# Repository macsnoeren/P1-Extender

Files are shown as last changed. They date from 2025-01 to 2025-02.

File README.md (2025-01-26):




# P1-Extender

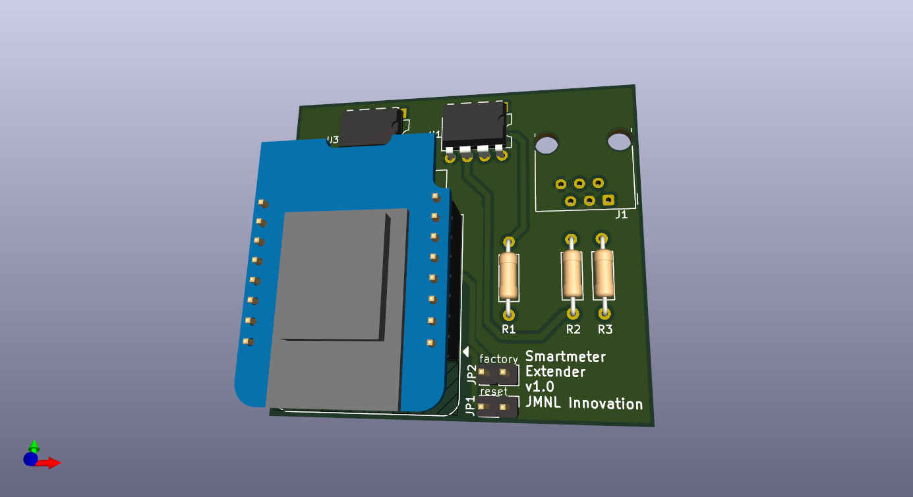
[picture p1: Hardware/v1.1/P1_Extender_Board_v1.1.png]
P1-Extender-Board


## Need your smart meter P1 port far away?
When you charging point is far away from your smartmeter and it needs a P1 poort connection to perform load balancing AND you are not able to use long wires? Than you can use this P1 extender. It connects with the network or Internet and read the messages from your smart meter (using another smart meter P1 reader). It provide these messages similarly to the smart meter. Just connect your charger point to this remote P1 port and it will get the P1 messages.

The hardware and software simulate a smart meter P1 port.

-- In progress

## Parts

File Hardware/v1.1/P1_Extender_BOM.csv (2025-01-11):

Reference | Value | Datasheet | Footprint | Qty | DNP
J1 | RJ12 | ~ | Connector_RJ:RJ12_Amphenol_54601-x06_Horizontal | 1
JP1 | Reset | ~ | Connector_PinHeader_2.54mm:PinHeader_1x02_P2.54mm_Vertical | 1
R1 | 165-200 (180) | ~ | Resistor_THT:R_Axial_DIN0207_L6.3mm_D2.5mm_P10.16mm_Horizontal | 1
R2 | 100 | ~ | Resistor_THT:R_Axial_DIN0207_L6.3mm_D2.5mm_P10.16mm_Horizontal | 1
R3 | 220-330 (330) | ~ | Resistor_THT:R_Axial_DIN0207_L6.3mm_D2.5mm_P10.16mm_Horizontal | 1
U1,U3 | 6N137 | https://docs.broadcom.com/docs/AV02-0940EN | Package_DIP:DIP-8_W7.62mm | 2
U2 | WeMos_D1_mini | https://wiki.wemos.cc/products:d1:d1_mini#documentation | Module:WEMOS_D1_mini_light | 1

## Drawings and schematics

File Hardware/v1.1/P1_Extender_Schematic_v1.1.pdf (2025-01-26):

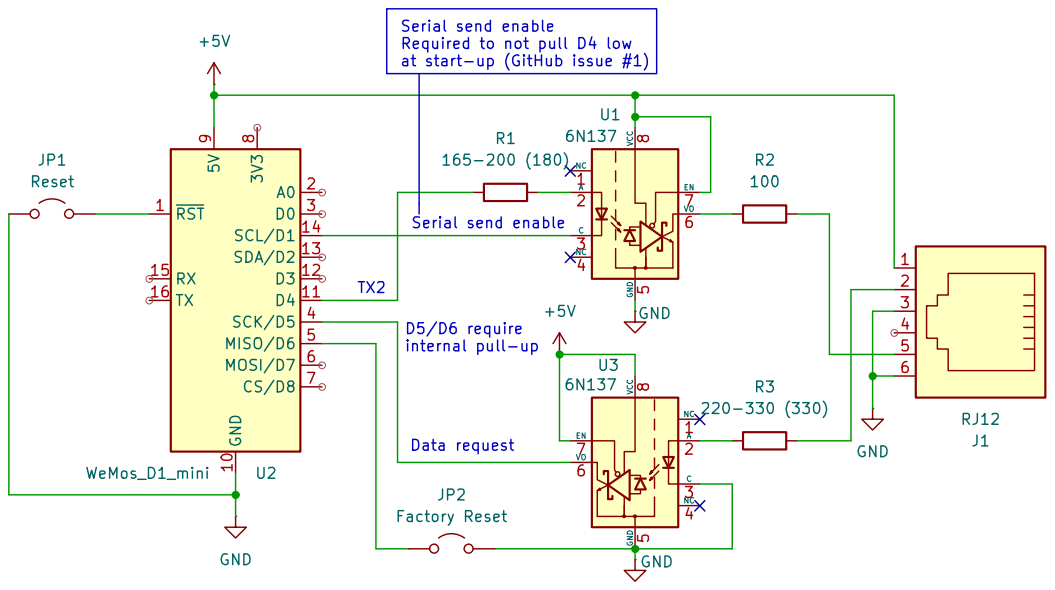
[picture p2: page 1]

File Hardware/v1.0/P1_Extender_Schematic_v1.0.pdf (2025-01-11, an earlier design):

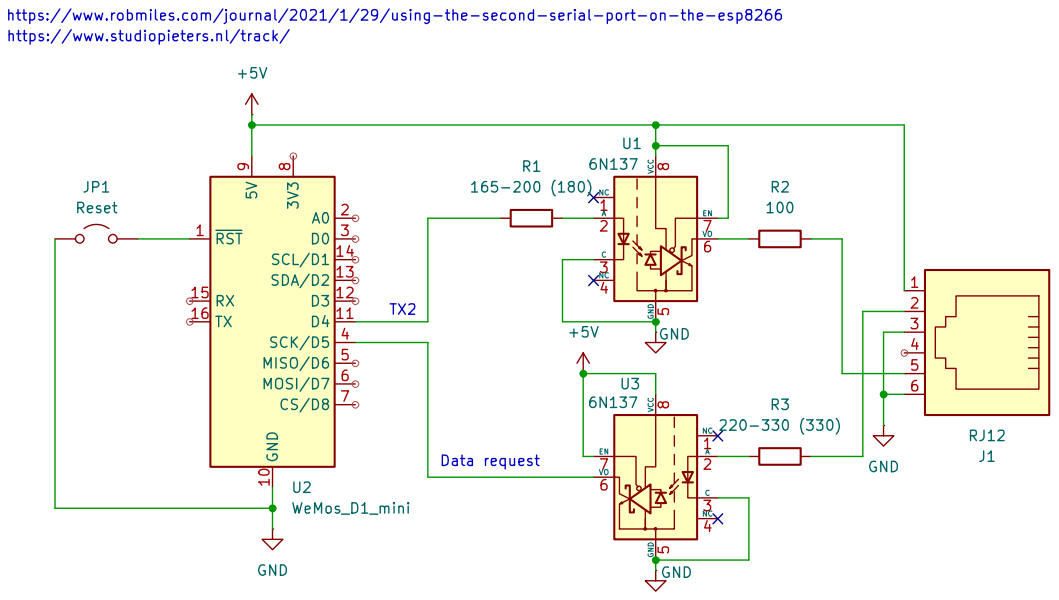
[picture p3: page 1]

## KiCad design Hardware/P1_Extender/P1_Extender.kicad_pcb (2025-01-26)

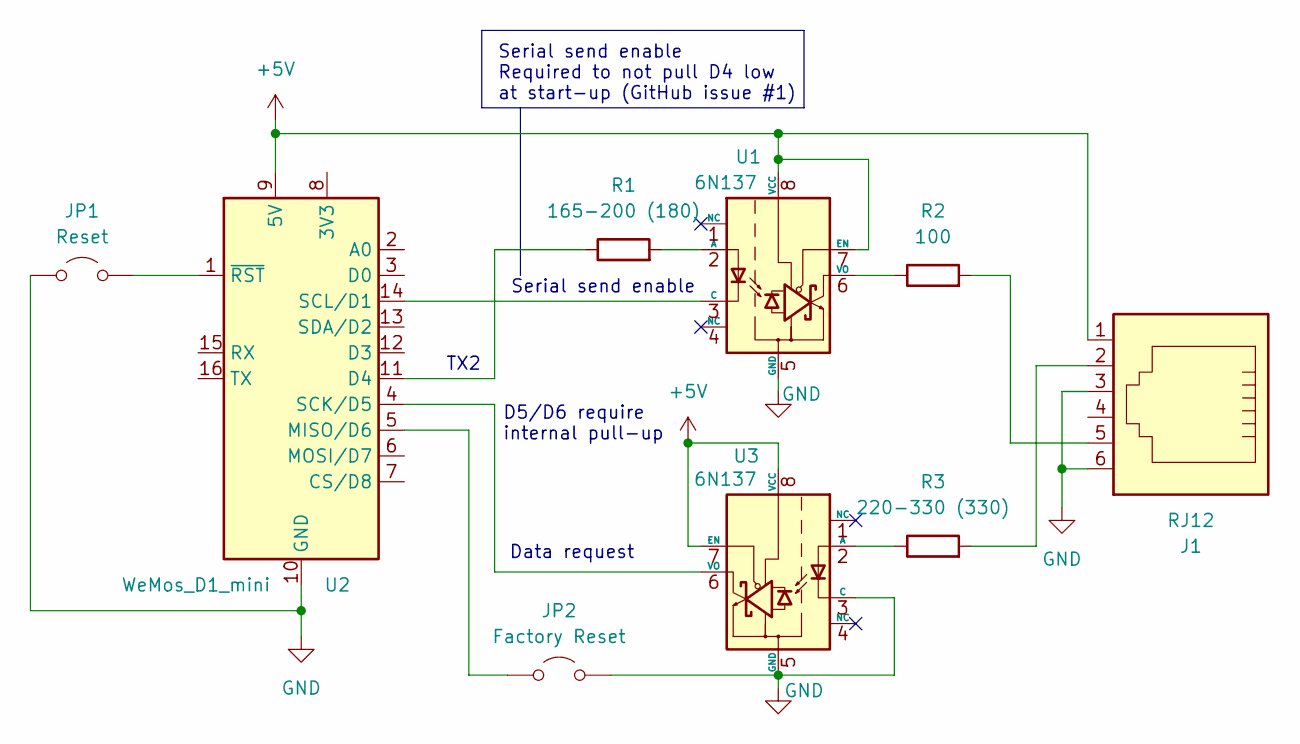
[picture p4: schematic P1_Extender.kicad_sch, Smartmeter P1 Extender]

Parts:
J1: RJ12; RJ12_Amphenol_54601-x06_Horizontal
JP1: Reset; PinHeader_1x02_P2.54mm_Vertical
JP2: Factory Reset; PinHeader_1x02_P2.54mm_Vertical
R1: 165-200 (180); R_Axial_DIN0207_L6.3mm_D2.5mm_P10.16mm_Horizontal
R2: 100; R_Axial_DIN0207_L6.3mm_D2.5mm_P10.16mm_Horizontal
R3: 220-330 (330); R_Axial_DIN0207_L6.3mm_D2.5mm_P10.16mm_Horizontal
U1, U3: 6N137; DIP-8_W7.62mm
U2: WeMos_D1_mini; WEMOS_D1_mini_light

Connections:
+5V: J1.1, U1.7 (EN), U1.8 (VCC), U2.9 (5V), U3.7 (EN), U3.8 (VCC)
GND: J1.3, J1.6, JP1.1 (A), JP2.2 (B), U1.5 (GND), U2.10 (GND), U3.3 (C), U3.5 (GND)
unnamed: J1.2, R3.2
unnamed: J1.5, R2.2
unnamed: JP1.2 (B), U2.1 (~RST)
unnamed: JP2.1 (A), U2.5 (MISO/D6)
unnamed: R1.2, U1.2 (A)
unnamed: U1.3 (C), U2.14 (SCL/D1)
unnamed: R2.1, U1.6 (VO)
unnamed: R1.1, U2.11 (D4)
unnamed: U2.4 (SCK/D5), U3.6 (VO)
unnamed: R3.1, U3.2 (A)

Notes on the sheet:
TX2
Serial send enable Required to not pull D4 low at start-up (GitHub issue #1)
Data request
Serial send enable
D5/D6 require internal pull-up

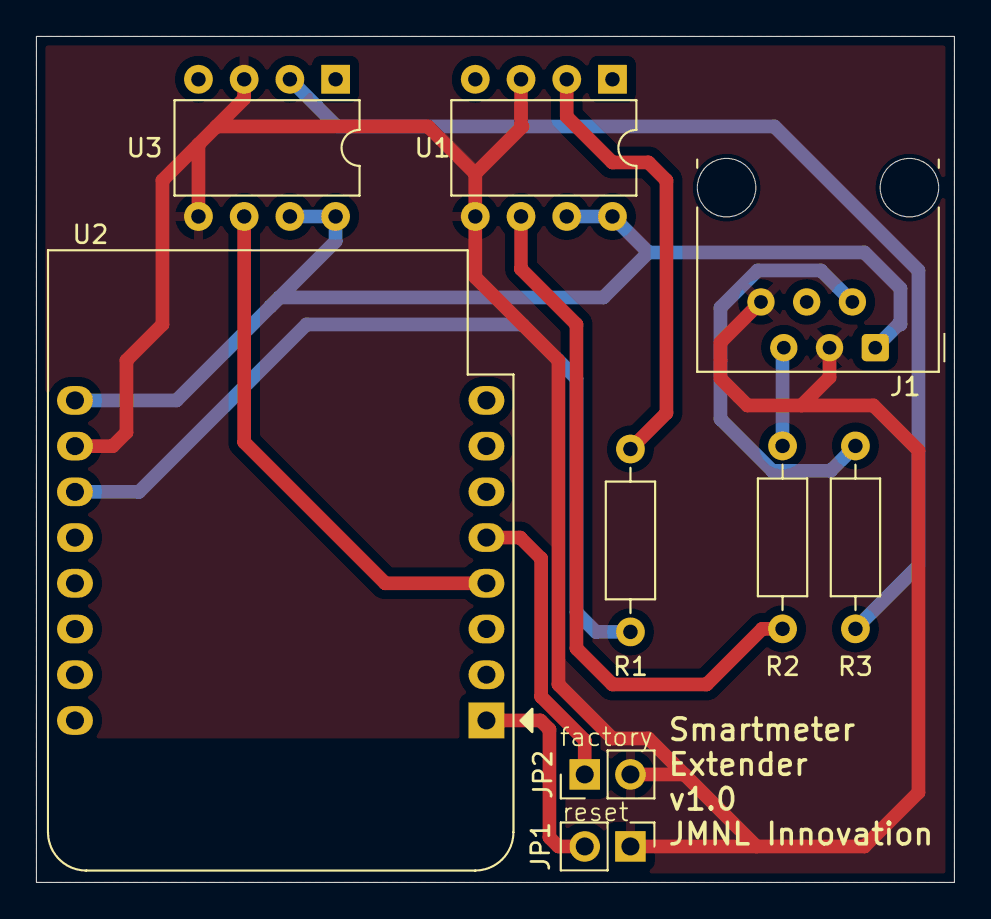
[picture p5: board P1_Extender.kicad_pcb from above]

Board: 2 copper layers, 51.0 x 47.0 mm, 9 parts (0 on the bottom side), 12 nets.

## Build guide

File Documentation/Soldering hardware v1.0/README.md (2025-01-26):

# Soldering the hardware version 1.0 and 1.1

The image below shows the components that are used to create the P1 Extender. Not many components. Using these components it is possible to simulate a smartmeter.

Note: For version 1.1 hardware no components have been added. So the process will be exactly the same.

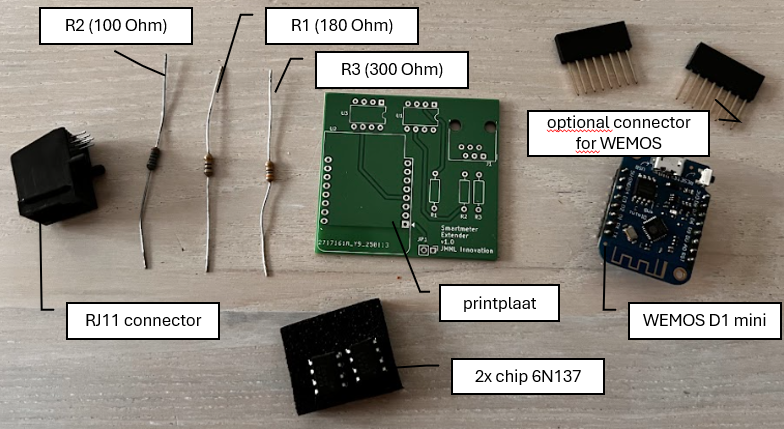
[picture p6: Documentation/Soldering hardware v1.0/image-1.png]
P1 Extender Hardware


## Step 1 Solder the resistors

Make sure you check the resistor values and place them at the right spot!

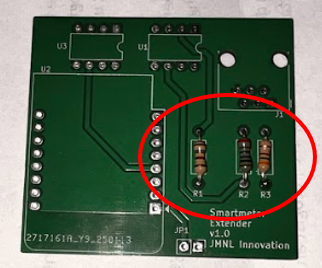
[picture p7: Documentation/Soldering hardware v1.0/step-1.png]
Step 1


## Step 2 Solder the 6N137 opto coupler chips

Pin one it marked on the print (square pin pad) and pin one is marked on the chip (a dot). Make sure you place it right!

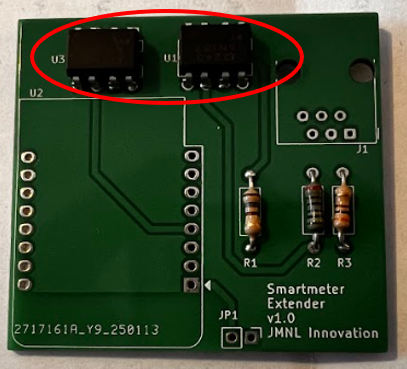
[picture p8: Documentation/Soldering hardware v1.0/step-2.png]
Step 2


## Step 3 Solder the WEMOS D1 mini

The WEMOS come with header pins. You can optionally place female headers, so it is possible to remove the WEMOS if required. I find that very usefull. In any case, you need to solder male header pins on the WEMOS. Using these header pins you are able to solder the WEMOS to the print. The figure below shows the female header on the print and the WEMOS male header.

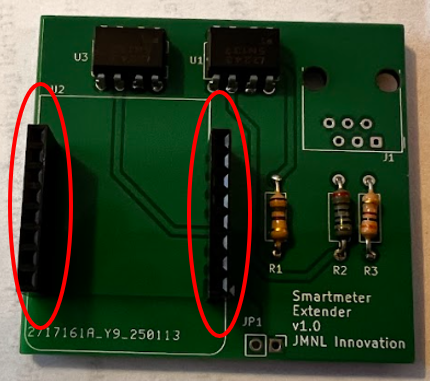
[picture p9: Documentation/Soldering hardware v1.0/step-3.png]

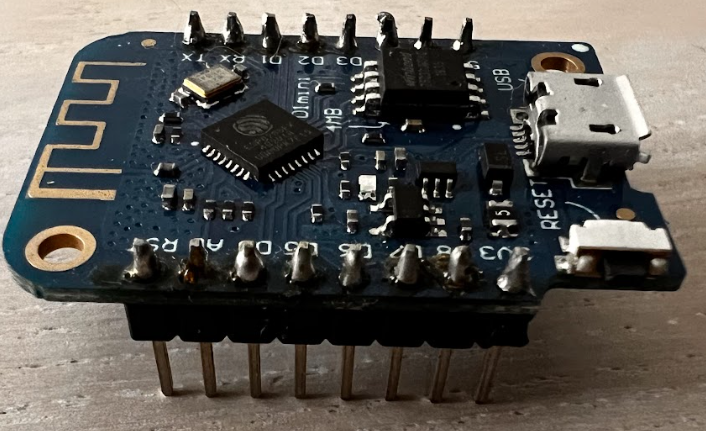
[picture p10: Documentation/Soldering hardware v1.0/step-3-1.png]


## Step 4 Solder RJ11 connector

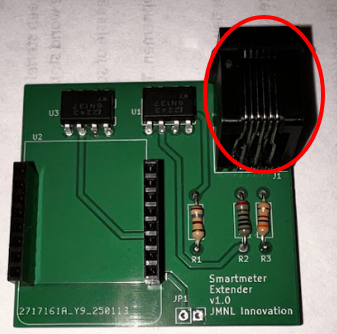
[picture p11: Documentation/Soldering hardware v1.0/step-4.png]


## Putting everything together

Place your WEMOS and it should look like the images below.

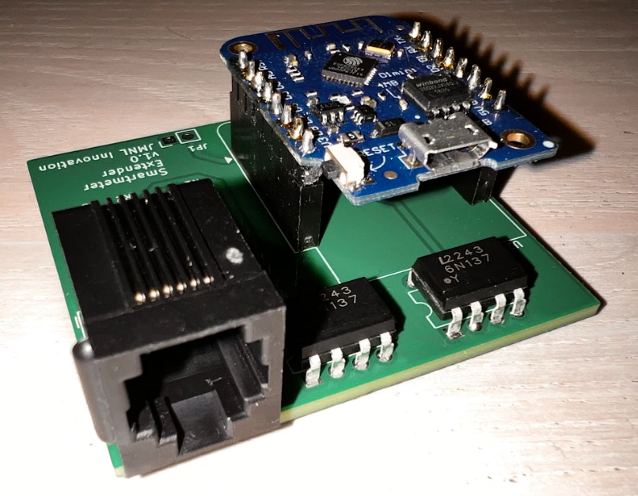
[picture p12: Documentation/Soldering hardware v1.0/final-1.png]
Final image 1

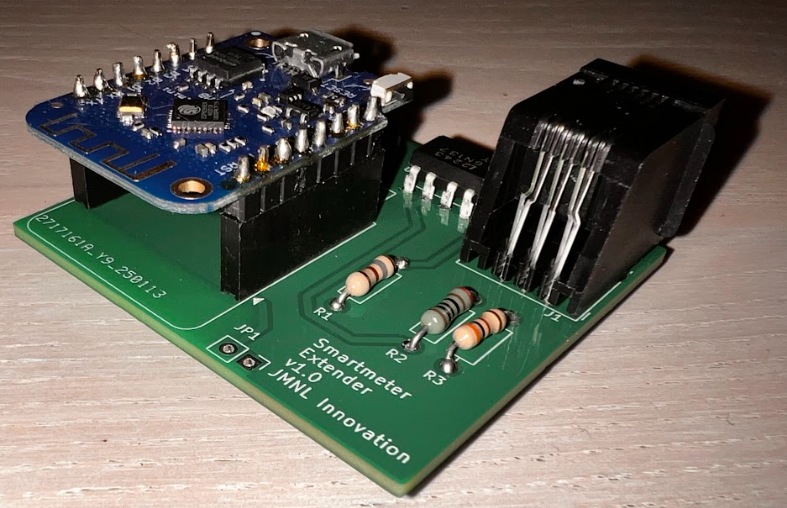
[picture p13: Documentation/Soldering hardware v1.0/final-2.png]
Final image 2

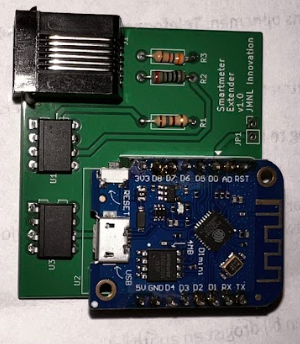
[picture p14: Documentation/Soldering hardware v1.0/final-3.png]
Final image 3


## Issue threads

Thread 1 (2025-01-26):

Hardware D4 is pulled low at start, so the boot fails

macsnoeren, 2025-01-26:
When the Wemos D1 mini is connected to the hardware, the boot fails. The chip will then not execute the code. The root cause is that D4 pin is pulled low at started. That result into a failed boot. This is explained on the webpage: https://lastminuteengineers.com/wemos-d1-mini-pinout-reference/ for more information.

macsnoeren, 2025-01-26:
The new hardware version v1.1 has solved this issue. Created a serial send enable that needs to be set to low as an output pin. At start-up the D4 pin will not be driven low anymore. The boot will than not fail anymore.

Closed 2025-01-26.

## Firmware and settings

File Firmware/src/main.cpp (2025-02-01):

/*
  - How to get the Wemos installed in the Ardiuno IDE: https://siytek.com/wemos-d1-mini-arduino-wifi/
  - Install library WiFiManager by tablatronics: https://github.com/tzapu/WiFiManager
  - Install library JsonArduino by Banoit Blanchon: https://arduinojson.org/?utm_source=meta&utm_medium=library.properties
  - Install library knolleary/PubSubClient by Nick O'Leary: https://github.com/knolleary/pubsubclient
*/
#include <Arduino.h>

#include <ESP8266WiFi.h>
#include <ESP8266WebServer.h>
#include <WiFiClient.h>
#include <WiFiManager.h>
#include <PubSubClient.h>
#include <ArduinoJson.h>
#include <LittleFS.h>

#define DATA_REQUEST_PIN D5
#define SERIAL_SEND_ENABLE_PIN D1
#define FACTORY_RESET_PIN D6

#define P1_TELEGRAM_SIZE 2048
#define P1_MAX_DATAGRAM_SIZE 2048
#define MQTT_USERNAME_LENGTH 32
#define MQTT_PASSWORD_LENGTH 32
#define MQTT_ID_TOKEN_LENGTH 64
#define MQTT_TOPIC_STRING_LENGTH 64
#define MQTT_REMOTE_HOST_LENGTH 128
#define MQTT_REMOTE_PORT_LENGTH 10
#define P1_BAUDRATE_LENGTH 10

#define MQTT_USERNAME "smartmeter"
#define MQTT_PASSWORD "se_smartmeter"
#define MQTT_REMOTE_HOST "sendlab.nl"
#define MQTT_REMOTE_PORT "11883"
#define MQTT_TOPIC "smartmeter/raw"
#define MQTT_MSGBUF_SIZE 2048

// Create struct for application config.
typedef struct {
   char     mqtt_username[MQTT_USERNAME_LENGTH];
   char     mqtt_password[MQTT_PASSWORD_LENGTH];
   char     mqtt_id[MQTT_ID_TOKEN_LENGTH];
   char     mqtt_topic[MQTT_TOPIC_STRING_LENGTH];
   char     mqtt_remote_host[MQTT_REMOTE_HOST_LENGTH];
   char     mqtt_remote_port[MQTT_REMOTE_PORT_LENGTH];
   char     p1_baudrate[P1_BAUDRATE_LENGTH];
} APP_CONFIG_STRUCT;

// Global variables
WiFiManager wifiManager;
bool shouldSaveConfig = false;
WiFiClient wifiClient;
WiFiClient tcpServerClient;
PubSubClient mqttClient("", 0, wifiClient); // Only with some dummy values seems to work ... instead of mqttClient();
char p1[P1_MAX_DATAGRAM_SIZE]; // Complete P1 telegram
uint8_t p1State = 0;
uint16_t p1Pointer = 0;
uint32_t p1Timer = 0;
APP_CONFIG_STRUCT app_config;
char mqtt_topic[128];

bool deleteAppConfig() {
  if( LittleFS.begin() ) {
    if( LittleFS.exists("/config.json") ) {
      if( LittleFS.remove("/config.json") ) {
        return true;
      }
    }
  } 
  return false;
}

void create_unique_mqtt_topic_string (char *topic_string) {
   char tmp[30];
   strcpy(topic_string,"P1EXT-V01");
   sprintf(tmp,"-%06X",ESP.getChipId());
   strcat(topic_string,tmp);
   sprintf(tmp,"-%06X",ESP.getFlashChipId()); 
   strcat(topic_string,tmp);
}

void create_unigue_mqtt_id (char *signature) {
   char tmp[30];
   strcpy(signature,"2025-P1-EXT");
   strcat(signature,"-V01");
   sprintf(tmp,"-%06X",ESP.getChipId());
   strcat(signature,tmp);
   sprintf(tmp,"-%06X",ESP.getFlashChipId()); 
   strcat(signature,tmp);
}

void factoryDefault () {
  wifiManager.resetSettings();
  deleteAppConfig();
  delay(2000);
  ESP.reset();
}

bool readAppConfig(APP_CONFIG_STRUCT *app_config) {
  if( LittleFS.begin() ) {
    if( LittleFS.exists("/config.json") ) {
       File configFile = LittleFS.open("/config.json","r");
       if( configFile ) {

          size_t size = configFile.size();
          if (size > 1024) {
            Serial.println("Config file size is too large");
          }

          std::unique_ptr<char[]> buf(new char[size]);
          configFile.readBytes(buf.get(), size);
        
          JsonDocument doc;
          DeserializationError error = deserializeJson(doc, buf.get());
          
          if( error == DeserializationError::Ok ) {
             strcpy(app_config->mqtt_username, doc["MQTT_USERNAME"]);
             strcpy(app_config->mqtt_password, doc["MQTT_PASSWORD"]);
             strcpy(app_config->mqtt_remote_host, doc["MQTT_HOST"]);
             strcpy(app_config->mqtt_remote_port, doc["MQTT_PORT"]);
             strcpy(app_config->p1_baudrate, doc["P1_BAUDRATE"]);
             return true;
          }
       }
    }
  }  
  return false;
}

bool writeAppConfig(APP_CONFIG_STRUCT *app_config) {
  deleteAppConfig(); // Delete config file if exists

  JsonDocument doc;
  doc["MQTT_USERNAME"] = app_config->mqtt_username;
  doc["MQTT_PASSWORD"] = app_config->mqtt_password;
  doc["MQTT_HOST"] = app_config->mqtt_remote_host;
  doc["MQTT_PORT"] = app_config->mqtt_remote_port;
  doc["P1_BAUDRATE"]= app_config->p1_baudrate;
  
  File configFile = LittleFS.open("/config.json","w+");
  if( configFile ) {
     serializeJson(doc, configFile);
     configFile.close();
     return true;
  }    
  return false;
}

void saveConfigCallback () {
  shouldSaveConfig = true;
}

void setup() {
  // Configure the serial port
  Serial.begin(115200); // open the port at 19200 baud
  Serial.println("\nP1 Extender setup...");

  // Configure the data request pin as input and enable the internal pull-up resistor.
  pinMode(D4, OUTPUT); // Serial 1 output
  pinMode(DATA_REQUEST_PIN, INPUT_PULLUP);
  pinMode(FACTORY_RESET_PIN, INPUT_PULLUP);
  pinMode(SERIAL_SEND_ENABLE_PIN, OUTPUT);
  digitalWrite(SERIAL_SEND_ENABLE_PIN, LOW); // Enable the serial send.

  if ( digitalRead(FACTORY_RESET_PIN) == LOW ) { // If pull low at start-up, start the factory default functionality
  Serial.println("Go to factory defaults!!");
    factoryDefault();
  }

  // Setup unique mqtt id and mqtt topic string
  create_unique_mqtt_topic_string(app_config.mqtt_topic);
  create_unigue_mqtt_id(app_config.mqtt_id);
  sprintf(mqtt_topic, MQTT_TOPIC);

  // Read config file or generate default
  if( !readAppConfig(&app_config) ) {
    strcpy(app_config.mqtt_username, MQTT_USERNAME);
    strcpy(app_config.mqtt_password, MQTT_PASSWORD);
    strcpy(app_config.mqtt_remote_host, MQTT_REMOTE_HOST);
    strcpy(app_config.mqtt_remote_port, MQTT_REMOTE_PORT);
    strcpy(app_config.p1_baudrate, "115200");
    writeAppConfig(&app_config);
  }

  wifiManager.setMinimumSignalQuality(20);
  wifiManager.setTimeout(300);
  wifiManager.setSaveConfigCallback(saveConfigCallback);

  // Adds some parameters to the default webpage
  WiFiManagerParameter wmp_text("<br/>MQTT setting:</br>");
  wifiManager.addParameter(&wmp_text);
  WiFiManagerParameter custom_mqtt_username("mqtt_username", "Username", app_config.mqtt_username, MQTT_USERNAME_LENGTH);
  WiFiManagerParameter custom_mqtt_password("mqtt_password", "Password", app_config.mqtt_password, MQTT_PASSWORD_LENGTH);
  WiFiManagerParameter custom_mqtt_remote_host("mqtt_remote_host", "Host", app_config.mqtt_remote_host, MQTT_REMOTE_HOST_LENGTH);
  WiFiManagerParameter custom_mqtt_remote_port("mqtt_remote_port", "Port", app_config.mqtt_remote_port, MQTT_REMOTE_PORT_LENGTH);
  WiFiManagerParameter custom_p1_baudrate("p1_baudrate", "Baudrate", app_config.p1_baudrate, P1_BAUDRATE_LENGTH);

  wifiManager.addParameter(&custom_mqtt_username);
  wifiManager.addParameter(&custom_mqtt_password);
  wifiManager.addParameter(&custom_mqtt_remote_host);
  wifiManager.addParameter(&custom_mqtt_remote_port);
  wifiManager.addParameter(&custom_p1_baudrate);

  // Add the unit ID to the webpage
  char fd_str[128]="<p>Your P1 Extender ID: <b>";
  strcat(fd_str, app_config.mqtt_topic);
  strcat(fd_str, "</b> Make a SCREENSHOT - you will need this info later!</p>");
  WiFiManagerParameter mqqt_topic_text(fd_str);
  wifiManager.addParameter(&mqqt_topic_text);

  if( !wifiManager.autoConnect("P1 Extender")) {
    delay(1000);
    ESP.reset();
  }

  if ( shouldSaveConfig ) {
    strcpy(app_config.mqtt_username, custom_mqtt_username.getValue());
    strcpy(app_config.mqtt_password, custom_mqtt_password.getValue());
    strcpy(app_config.mqtt_remote_host, custom_mqtt_remote_host.getValue());
    strcpy(app_config.mqtt_remote_port, custom_mqtt_remote_port.getValue());
    strcpy(app_config.p1_baudrate, custom_p1_baudrate.getValue());
    writeAppConfig(&app_config);
  }

  Serial.printf("\n");
  Serial.printf("************ P1 Extender ********************\n");
  Serial.printf("ESP8266 info\n");
  Serial.printf("\tSDK Version     : %s\n", ESP.getSdkVersion() );
  Serial.printf("\tCore Version    : %s\n", ESP.getCoreVersion().c_str() );
  Serial.printf("\tCore Frequency  : %d Mhz\n", ESP.getCpuFreqMHz());
  Serial.printf("\tLast reset      : %s\n", ESP.getResetReason().c_str() );

  Serial.printf("MQTT settings\n");
  Serial.printf("\tmqtt_username   : %s\n", app_config.mqtt_username);
  Serial.printf("\tmqtt_password   : %s\n", app_config.mqtt_password);
  Serial.printf("\tmqtt_id         : %s\n", app_config.mqtt_id);
  Serial.printf("\tmqtt_topic      : %s\n", mqtt_topic);
  Serial.printf("\tmqtt_remote_host: %s\n", app_config.mqtt_remote_host);
  Serial.printf("\tmqtt_remote_port: %s\n", app_config.mqtt_remote_port);

  Serial.printf("DSMR settings\n");
  Serial.printf("\tP1 Baudrate     : %s baud\n", app_config.p1_baudrate);
  Serial.printf("************ P1 Extender ********************\n");

  // Configure the second (half) serial port
  // https://www.robmiles.com/journal/2021/1/29/using-the-second-serial-port-on-the-esp8266
  Serial1.begin(atol(app_config.p1_baudrate), SERIAL_8N1); // simulating the smart meter on port D4

  // Allow bootloader to connect: do not remove!
  delay(2000);

  // Set p1 timer timeout
  p1Timer = millis();
}

bool isDataRequest () {
  return digitalRead(DATA_REQUEST_PIN) == LOW; // If enabled, the pin will be low
}

void mqtt_callback (char* topic, byte* payload, unsigned int length) {
  Serial.println("mqtt_callback: not implemented!");
}

void mqtt_connect () {
  if ( !mqttClient.connected() ) {
    char *host = app_config.mqtt_remote_host;
    int port = atoi(app_config.mqtt_remote_port);
    
    mqttClient.setClient(wifiClient);
    mqttClient.setServer(host, port );
    mqttClient.setBufferSize(MQTT_MSGBUF_SIZE);
    if ( mqttClient.connect(app_config.mqtt_id, app_config.mqtt_username, app_config.mqtt_password) ) {

      // Subscribe to mqtt topic
      mqttClient.subscribe(mqtt_topic);

      // Set callback
      mqttClient.setCallback(mqtt_callback);
      Serial.printf("%s: MQTT connected to %s:%d\n", __FUNCTION__, host, port);

    } else {
      Serial.printf("%s: MQTT connection ERROR (%s:%d)\n", __FUNCTION__, host, port);
    }
  }
}

bool captureP1 () {
  if ( tcpServerClient.connected() && tcpServerClient.available() ) {
    while ( tcpServerClient.available() ) {
      char c = tcpServerClient.read();
      switch(p1State) {
        case 0: // state start
          if ( c == '/' ) {
            p1[p1Pointer] = c;
            p1Pointer++;
            p1State = 1;
          }
          break;
        case 1: // state read message
          p1[p1Pointer] = c;
          p1Pointer++;
          if ( c == '!' ) {
            p1State = 2;
          }
          break;
        case 2: // End
          p1[p1Pointer] = c;
          p1Pointer++;
          if ( c == '\n' ) {
            p1[p1Pointer] = '\0';
            p1Pointer = 0;
            p1State = 0;
            return true;
          }
          break;
      }
      if ( p1Pointer >= P1_MAX_DATAGRAM_SIZE ) {
        Serial.println("captureP1: Buffer overflow detected.");
        p1Pointer = 0;
        p1State = 0;
        tcpServerClient.flush();
        return false;
      }
    }
  }

  return false;
}

void loop () {
  if( WiFi.status() == WL_CONNECTED) {
    /*if( !mqttClient.connected() ) {
      Serial.printf("State: %d\n", mqttClient.state());
      mqtt_connect();
      delay(1000);
    }*/
  }

  // Handel the MQTT
  //mqttClient.loop();
  
  // Connect to the p1 data server
  if ( !tcpServerClient.connected() ) {
    delay(1000);
//  if ( tcpServerClient.connect("192.168.2.80", 3141) ) {
    if ( tcpServerClient.connect("diy_smartmeter.local", 3141) ) {
      char message[100];
      size_t len = tcpServerClient.readBytesUntil('\n', message, 100); // Read the first message 'Smartmeter'
      message[len] = '\0';
      Serial.printf("wifiClient: Connected: '%s'\n", message);

    } else {
      Serial.println("wifiClient: Could not establish the connection.");
    }
    p1Timer = millis(); // No timer required here!
  }

  // Get the p1 message
  if ( captureP1() ) {
    //Serial.printf("P1: '%s'\n", p1);
    if ( isDataRequest() ) {
      Serial.println("Recieved P1 and forward P1");
      Serial1.print(p1);
    } else {
      Serial.println("Recieved P1");
    }
    p1Timer = millis();
  }

  // Check p1 timeout
  if ( millis() > p1Timer + 10000 ) {
    Serial.println("P1: Timeout...");
    tcpServerClient.flush();
    tcpServerClient.stop();
    p1Timer = millis();
  }

}

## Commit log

2025-01-11 Initial commit containing the hardware version 1.0
    [P1_Extender-B_Cu.gbl, P1_Extender-B_Mask.gbs, P1_Extender-B_Paste.gbp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]
2025-01-26 Added a draft version of the firmware and soldering documentation
2025-01-26 Fixed pull-up for D5 and added data request logic
    [main.cpp]
2025-01-26 Added new hardware version to fix the issues
    [P1_Extender-B_Cu.gbl, P1_Extender-B_Mask.gbs, P1_Extender-B_Paste.gbp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]
2025-01-27 First connection with the MQTT broker
    [main.cpp]
